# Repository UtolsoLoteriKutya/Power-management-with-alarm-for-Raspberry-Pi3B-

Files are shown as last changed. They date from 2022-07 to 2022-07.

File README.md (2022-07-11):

<html xmlns:v="urn:schemas-microsoft-com:vml"
xmlns:o="urn:schemas-microsoft-com:office:office"
xmlns:w="urn:schemas-microsoft-com:office:word"
xmlns:m="http://schemas.microsoft.com/office/2004/12/omml"
xmlns="http://www.w3.org/TR/REC-html40">

<head>
<meta http-equiv=Content-Type content="text/html; charset=windows-1250">
<meta name=ProgId content=Word.Document>
<meta name=Generator content="Microsoft Word 15">
<meta name=Originator content="Microsoft Word 15">
<link rel=File-List href="index_elemei/filelist.xml">
<link rel=Edit-Time-Data href="index_elemei/editdata.mso">
<!--[if !mso]>

<![endif]--><!--[if gte mso 9]><xml>
 <o:DocumentProperties>
  <o:Author>Citrák János</o:Author>
  <o:LastAuthor>Citrák János</o:LastAuthor>
  <o:Revision>5</o:Revision>
  <o:Created>2022-07-11T07:24:00Z</o:Created>
  <o:LastSaved>2022-07-11T10:03:00Z</o:LastSaved>
  <o:Pages>1</o:Pages>
  <o:Words>778</o:Words>
  <o:Characters>4903</o:Characters>
  <o:Lines>40</o:Lines>
  <o:Paragraphs>11</o:Paragraphs>
  <o:CharactersWithSpaces>5670</o:CharactersWithSpaces>
  <o:Version>16.00</o:Version>
 </o:DocumentProperties>
 <o:OfficeDocumentSettings>
  <o:AllowPNG/>
 </o:OfficeDocumentSettings>
</xml><![endif]-->
<link rel=themeData href="index_elemei/themedata.thmx">
<link rel=colorSchemeMapping href="index_elemei/colorschememapping.xml">
<!--[if gte mso 9]><xml>
 <w:WordDocument>
  <w:Zoom>90</w:Zoom>
  <w:TrackMoves>false</w:TrackMoves>
  <w:TrackFormatting/>
  <w:HyphenationZone>21</w:HyphenationZone>
  <w:PunctuationKerning/>
  <w:ValidateAgainstSchemas/>
  <w:SaveIfXMLInvalid>false</w:SaveIfXMLInvalid>
  <w:IgnoreMixedContent>false</w:IgnoreMixedContent>
  <w:AlwaysShowPlaceholderText>false</w:AlwaysShowPlaceholderText>
  <w:DoNotPromoteQF/>
  <w:LidThemeOther>DE</w:LidThemeOther>
  <w:LidThemeAsian>X-NONE</w:LidThemeAsian>
  <w:LidThemeComplexScript>AR-SA</w:LidThemeComplexScript>
  <w:Compatibility>
   <w:BreakWrappedTables/>
   <w:SnapToGridInCell/>
   <w:WrapTextWithPunct/>
   <w:UseAsianBreakRules/>
   <w:DontGrowAutofit/>
   <w:SplitPgBreakAndParaMark/>
   <w:EnableOpenTypeKerning/>
   <w:DontFlipMirrorIndents/>
   <w:OverrideTableStyleHps/>
  </w:Compatibility>
  <m:mathPr>
   <m:mathFont m:val="Cambria Math"/>
   <m:brkBin m:val="before"/>
   <m:brkBinSub m:val="&#45;-"/>
   <m:smallFrac m:val="off"/>
   <m:dispDef/>
   <m:lMargin m:val="0"/>
   <m:rMargin m:val="0"/>
   <m:defJc m:val="centerGroup"/>
   <m:wrapIndent m:val="1440"/>
   <m:intLim m:val="subSup"/>
   <m:naryLim m:val="undOvr"/>
  </m:mathPr></w:WordDocument>
</xml><![endif]--><!--[if gte mso 9]><xml>
 <w:LatentStyles DefLockedState="false" DefUnhideWhenUsed="false"
  DefSemiHidden="false" DefQFormat="false" DefPriority="99"
  LatentStyleCount="376">
  <w:LsdException Locked="false" Priority="0" QFormat="true" Name="Normal"/>
  <w:LsdException Locked="false" Priority="9" QFormat="true" Name="heading 1"/>
  <w:LsdException Locked="false" Priority="9" SemiHidden="true"
   UnhideWhenUsed="true" QFormat="true" Name="heading 2"/>
  <w:LsdException Locked="false" Priority="9" SemiHidden="true"
   UnhideWhenUsed="true" QFormat="true" Name="heading 3"/>
  <w:LsdException Locked="false" Priority="9" SemiHidden="true"
   UnhideWhenUsed="true" QFormat="true" Name="heading 4"/>
  <w:LsdException Locked="false" Priority="9" SemiHidden="true"
   UnhideWhenUsed="true" QFormat="true" Name="heading 5"/>
  <w:LsdException Locked="false" Priority="9" SemiHidden="true"
   UnhideWhenUsed="true" QFormat="true" Name="heading 6"/>
  <w:LsdException Locked="false" Priority="9" SemiHidden="true"
   UnhideWhenUsed="true" QFormat="true" Name="heading 7"/>
  <w:LsdException Locked="false" Priority="9" SemiHidden="true"
   UnhideWhenUsed="true" QFormat="true" Name="heading 8"/>
  <w:LsdException Locked="false" Priority="9" SemiHidden="true"
   UnhideWhenUsed="true" QFormat="true" Name="heading 9"/>
  <w:LsdException Locked="false" SemiHidden="true" UnhideWhenUsed="true"
   Name="index 1"/>
  <w:LsdException Locked="false" SemiHidden="true" UnhideWhenUsed="true"
   Name="index 2"/>
  <w:LsdException Locked="false" SemiHidden="true" UnhideWhenUsed="true"
   Name="index 3"/>
  <w:LsdException Locked="false" SemiHidden="true" UnhideWhenUsed="true"
   Name="index 4"/>
  <w:LsdException Locked="false" SemiHidden="true" UnhideWhenUsed="true"
   Name="index 5"/>
  <w:LsdException Locked="false" SemiHidden="true" UnhideWhenUsed="true"
   Name="index 6"/>
  <w:LsdException Locked="false" SemiHidden="true" UnhideWhenUsed="true"
   Name="index 7"/>
  <w:LsdException Locked="false" SemiHidden="true" UnhideWhenUsed="true"
   Name="index 8"/>
  <w:LsdException Locked="false" SemiHidden="true" UnhideWhenUsed="true"
   Name="index 9"/>
  <w:LsdException Locked="false" Priority="39" SemiHidden="true"
   UnhideWhenUsed="true" Name="toc 1"/>
  <w:LsdException Locked="false" Priority="39" SemiHidden="true"
   UnhideWhenUsed="true" Name="toc 2"/>
  <w:LsdException Locked="false" Priority="39" SemiHidden="true"
   UnhideWhenUsed="true" Name="toc 3"/>
  <w:LsdException Locked="false" Priority="39" SemiHidden="true"
   UnhideWhenUsed="true" Name="toc 4"/>
  <w:LsdException Locked="false" Priority="39" SemiHidden="true"
   UnhideWhenUsed="true" Name="toc 5"/>
  <w:LsdException Locked="false" Priority="39" SemiHidden="true"
   UnhideWhenUsed="true" Name="toc 6"/>
  <w:LsdException Locked="false" Priority="39" SemiHidden="true"
   UnhideWhenUsed="true" Name="toc 7"/>
  <w:LsdException Locked="false" Priority="39" SemiHidden="true"
   UnhideWhenUsed="true" Name="toc 8"/>
  <w:LsdException Locked="false" Priority="39" SemiHidden="true"
   UnhideWhenUsed="true" Name="toc 9"/>
  <w:LsdException Locked="false" SemiHidden="true" UnhideWhenUsed="true"
   Name="Normal Indent"/>
  <w:LsdException Locked="false" SemiHidden="true" UnhideWhenUsed="true"
   Name="footnote text"/>
  <w:LsdException Locked="false" SemiHidden="true" UnhideWhenUsed="true"
   Name="annotation text"/>
  <w:LsdException Locked="false" SemiHidden="true" UnhideWhenUsed="true"
   Name="header"/>
  <w:LsdException Locked="false" SemiHidden="true" UnhideWhenUsed="true"
   Name="footer"/>
  <w:LsdException Locked="false" SemiHidden="true" UnhideWhenUsed="true"
   Name="index heading"/>
  <w:LsdException Locked="false" Priority="35" SemiHidden="true"
   UnhideWhenUsed="true" QFormat="true" Name="caption"/>
  <w:LsdException Locked="false" SemiHidden="true" UnhideWhenUsed="true"
   Name="table of figures"/>
  <w:LsdException Locked="false" SemiHidden="true" UnhideWhenUsed="true"
   Name="envelope address"/>
  <w:LsdException Locked="false" SemiHidden="true" UnhideWhenUsed="true"
   Name="envelope return"/>
  <w:LsdException Locked="false" SemiHidden="true" UnhideWhenUsed="true"
   Name="footnote reference"/>
  <w:LsdException Locked="false" SemiHidden="true" UnhideWhenUsed="true"
   Name="annotation reference"/>
  <w:LsdException Locked="false" SemiHidden="true" UnhideWhenUsed="true"
   Name="line number"/>
  <w:LsdException Locked="false" SemiHidden="true" UnhideWhenUsed="true"
   Name="page number"/>
  <w:LsdException Locked="false" SemiHidden="true" UnhideWhenUsed="true"
   Name="endnote reference"/>
  <w:LsdException Locked="false" SemiHidden="true" UnhideWhenUsed="true"
   Name="endnote text"/>
  <w:LsdException Locked="false" SemiHidden="true" UnhideWhenUsed="true"
   Name="table of authorities"/>
  <w:LsdException Locked="false" SemiHidden="true" UnhideWhenUsed="true"
   Name="macro"/>
  <w:LsdException Locked="false" SemiHidden="true" UnhideWhenUsed="true"
   Name="toa heading"/>
  <w:LsdException Locked="false" SemiHidden="true" UnhideWhenUsed="true"
   Name="List"/>
  <w:LsdException Locked="false" SemiHidden="true" UnhideWhenUsed="true"
   Name="List Bullet"/>
  <w:LsdException Locked="false" SemiHidden="true" UnhideWhenUsed="true"
   Name="List Number"/>
  <w:LsdException Locked="false" SemiHidden="true" UnhideWhenUsed="true"
   Name="List 2"/>
  <w:LsdException Locked="false" SemiHidden="true" UnhideWhenUsed="true"
   Name="List 3"/>
  <w:LsdException Locked="false" SemiHidden="true" UnhideWhenUsed="true"
   Name="List 4"/>
  <w:LsdException Locked="false" SemiHidden="true" UnhideWhenUsed="true"
   Name="List 5"/>
  <w:LsdException Locked="false" SemiHidden="true" UnhideWhenUsed="true"
   Name="List Bullet 2"/>
  <w:LsdException Locked="false" SemiHidden="true" UnhideWhenUsed="true"
   Name="List Bullet 3"/>
  <w:LsdException Locked="false" SemiHidden="true" UnhideWhenUsed="true"
   Name="List Bullet 4"/>
  <w:LsdException Locked="false" SemiHidden="true" UnhideWhenUsed="true"
   Name="List Bullet 5"/>
  <w:LsdException Locked="false" SemiHidden="true" UnhideWhenUsed="true"
   Name="List Number 2"/>
  <w:LsdException Locked="false" SemiHidden="true" UnhideWhenUsed="true"
   Name="List Number 3"/>
  <w:LsdException Locked="false" SemiHidden="true" UnhideWhenUsed="true"
   Name="List Number 4"/>
  <w:LsdException Locked="false" SemiHidden="true" UnhideWhenUsed="true"
   Name="List Number 5"/>
  <w:LsdException Locked="false" Priority="10" QFormat="true" Name="Title"/>
  <w:LsdException Locked="false" SemiHidden="true" UnhideWhenUsed="true"
   Name="Closing"/>
  <w:LsdException Locked="false" SemiHidden="true" UnhideWhenUsed="true"
   Name="Signature"/>
  <w:LsdException Locked="false" Priority="1" SemiHidden="true"
   UnhideWhenUsed="true" Name="Default Paragraph Font"/>
  <w:LsdException Locked="false" SemiHidden="true" UnhideWhenUsed="true"
   Name="Body Text"/>
  <w:LsdException Locked="false" SemiHidden="true" UnhideWhenUsed="true"
   Name="Body Text Indent"/>
  <w:LsdException Locked="false" SemiHidden="true" UnhideWhenUsed="true"
   Name="List Continue"/>
  <w:LsdException Locked="false" SemiHidden="true" UnhideWhenUsed="true"
   Name="List Continue 2"/>
  <w:LsdException Locked="false" SemiHidden="true" UnhideWhenUsed="true"
   Name="List Continue 3"/>
  <w:LsdException Locked="false" SemiHidden="true" UnhideWhenUsed="true"
   Name="List Continue 4"/>
  <w:LsdException Locked="false" SemiHidden="true" UnhideWhenUsed="true"
   Name="List Continue 5"/>
  <w:LsdException Locked="false" SemiHidden="true" UnhideWhenUsed="true"
   Name="Message Header"/>
  <w:LsdException Locked="false" Priority="11" QFormat="true" Name="Subtitle"/>
  <w:LsdException Locked="false" SemiHidden="true" UnhideWhenUsed="true"
   Name="Salutation"/>
  <w:LsdException Locked="false" SemiHidden="true" UnhideWhenUsed="true"
   Name="Date"/>
  <w:LsdException Locked="false" SemiHidden="true" UnhideWhenUsed="true"
   Name="Body Text First Indent"/>
  <w:LsdException Locked="false" SemiHidden="true" UnhideWhenUsed="true"
   Name="Body Text First Indent 2"/>
  <w:LsdException Locked="false" SemiHidden="true" UnhideWhenUsed="true"
   Name="Note Heading"/>
  <w:LsdException Locked="false" SemiHidden="true" UnhideWhenUsed="true"
   Name="Body Text 2"/>
  <w:LsdException Locked="false" SemiHidden="true" UnhideWhenUsed="true"
   Name="Body Text 3"/>
  <w:LsdException Locked="false" SemiHidden="true" UnhideWhenUsed="true"
   Name="Body Text Indent 2"/>
  <w:LsdException Locked="false" SemiHidden="true" UnhideWhenUsed="true"
   Name="Body Text Indent 3"/>
  <w:LsdException Locked="false" SemiHidden="true" UnhideWhenUsed="true"
   Name="Block Text"/>
  <w:LsdException Locked="false" SemiHidden="true" UnhideWhenUsed="true"
   Name="Hyperlink"/>
  <w:LsdException Locked="false" SemiHidden="true" UnhideWhenUsed="true"
   Name="FollowedHyperlink"/>
  <w:LsdException Locked="false" Priority="22" QFormat="true" Name="Strong"/>
  <w:LsdException Locked="false" Priority="20" QFormat="true" Name="Emphasis"/>
  <w:LsdException Locked="false" SemiHidden="true" UnhideWhenUsed="true"
   Name="Document Map"/>
  <w:LsdException Locked="false" SemiHidden="true" UnhideWhenUsed="true"
   Name="Plain Text"/>
  <w:LsdException Locked="false" SemiHidden="true" UnhideWhenUsed="true"
   Name="E-mail Signature"/>
  <w:LsdException Locked="false" SemiHidden="true" UnhideWhenUsed="true"
   Name="HTML Top of Form"/>
  <w:LsdException Locked="false" SemiHidden="true" UnhideWhenUsed="true"
   Name="HTML Bottom of Form"/>
  <w:LsdException Locked="false" SemiHidden="true" UnhideWhenUsed="true"
   Name="Normal (Web)"/>
  <w:LsdException Locked="false" SemiHidden="true" UnhideWhenUsed="true"
   Name="HTML Acronym"/>
  <w:LsdException Locked="false" SemiHidden="true" UnhideWhenUsed="true"
   Name="HTML Address"/>
  <w:LsdException Locked="false" SemiHidden="true" UnhideWhenUsed="true"
   Name="HTML Cite"/>
  <w:LsdException Locked="false" SemiHidden="true" UnhideWhenUsed="true"
   Name="HTML Code"/>
  <w:LsdException Locked="false" SemiHidden="true" UnhideWhenUsed="true"
   Name="HTML Definition"/>
  <w:LsdException Locked="false" SemiHidden="true" UnhideWhenUsed="true"
   Name="HTML Keyboard"/>
  <w:LsdException Locked="false" SemiHidden="true" UnhideWhenUsed="true"
   Name="HTML Preformatted"/>
  <w:LsdException Locked="false" SemiHidden="true" UnhideWhenUsed="true"
   Name="HTML Sample"/>
  <w:LsdException Locked="false" SemiHidden="true" UnhideWhenUsed="true"
   Name="HTML Typewriter"/>
  <w:LsdException Locked="false" SemiHidden="true" UnhideWhenUsed="true"
   Name="HTML Variable"/>
  <w:LsdException Locked="false" SemiHidden="true" UnhideWhenUsed="true"
   Name="Normal Table"/>
  <w:LsdException Locked="false" SemiHidden="true" UnhideWhenUsed="true"
   Name="annotation subject"/>
  <w:LsdException Locked="false" SemiHidden="true" UnhideWhenUsed="true"
   Name="No List"/>
  <w:LsdException Locked="false" SemiHidden="true" UnhideWhenUsed="true"
   Name="Outline List 1"/>
  <w:LsdException Locked="false" SemiHidden="true" UnhideWhenUsed="true"
   Name="Outline List 2"/>
  <w:LsdException Locked="false" SemiHidden="true" UnhideWhenUsed="true"
   Name="Outline List 3"/>
  <w:LsdException Locked="false" SemiHidden="true" UnhideWhenUsed="true"
   Name="Table Simple 1"/>
  <w:LsdException Locked="false" SemiHidden="true" UnhideWhenUsed="true"
   Name="Table Simple 2"/>
  <w:LsdException Locked="false" SemiHidden="true" UnhideWhenUsed="true"
   Name="Table Simple 3"/>
  <w:LsdException Locked="false" SemiHidden="true" UnhideWhenUsed="true"
   Name="Table Classic 1"/>
  <w:LsdException Locked="false" SemiHidden="true" UnhideWhenUsed="true"
   Name="Table Classic 2"/>
  <w:LsdException Locked="false" SemiHidden="true" UnhideWhenUsed="true"
   Name="Table Classic 3"/>
  <w:LsdException Locked="false" SemiHidden="true" UnhideWhenUsed="true"
   Name="Table Classic 4"/>
  <w:LsdException Locked="false" SemiHidden="true" UnhideWhenUsed="true"
   Name="Table Colorful 1"/>
  <w:LsdException Locked="false" SemiHidden="true" UnhideWhenUsed="true"
   Name="Table Colorful 2"/>
  <w:LsdException Locked="false" SemiHidden="true" UnhideWhenUsed="true"
   Name="Table Colorful 3"/>
  <w:LsdException Locked="false" SemiHidden="true" UnhideWhenUsed="true"
   Name="Table Columns 1"/>
  <w:LsdException Locked="false" SemiHidden="true" UnhideWhenUsed="true"
   Name="Table Columns 2"/>
  <w:LsdException Locked="false" SemiHidden="true" UnhideWhenUsed="true"
   Name="Table Columns 3"/>
  <w:LsdException Locked="false" SemiHidden="true" UnhideWhenUsed="true"
   Name="Table Columns 4"/>
  <w:LsdException Locked="false" SemiHidden="true" UnhideWhenUsed="true"
   Name="Table Columns 5"/>
  <w:LsdException Locked="false" SemiHidden="true" UnhideWhenUsed="true"
   Name="Table Grid 1"/>
  <w:LsdException Locked="false" SemiHidden="true" UnhideWhenUsed="true"
   Name="Table Grid 2"/>
  <w:LsdException Locked="false" SemiHidden="true" UnhideWhenUsed="true"
   Name="Table Grid 3"/>
  <w:LsdException Locked="false" SemiHidden="true" UnhideWhenUsed="true"
   Name="Table Grid 4"/>
  <w:LsdException Locked="false" SemiHidden="true" UnhideWhenUsed="true"
   Name="Table Grid 5"/>
  <w:LsdException Locked="false" SemiHidden="true" UnhideWhenUsed="true"
   Name="Table Grid 6"/>
  <w:LsdException Locked="false" SemiHidden="true" UnhideWhenUsed="true"
   Name="Table Grid 7"/>
  <w:LsdException Locked="false" SemiHidden="true" UnhideWhenUsed="true"
   Name="Table Grid 8"/>
  <w:LsdException Locked="false" SemiHidden="true" UnhideWhenUsed="true"
   Name="Table List 1"/>
  <w:LsdException Locked="false" SemiHidden="true" UnhideWhenUsed="true"
   Name="Table List 2"/>
  <w:LsdException Locked="false" SemiHidden="true" UnhideWhenUsed="true"
   Name="Table List 3"/>
  <w:LsdException Locked="false" SemiHidden="true" UnhideWhenUsed="true"
   Name="Table List 4"/>
  <w:LsdException Locked="false" SemiHidden="true" UnhideWhenUsed="true"
   Name="Table List 5"/>
  <w:LsdException Locked="false" SemiHidden="true" UnhideWhenUsed="true"
   Name="Table List 6"/>
  <w:LsdException Locked="false" SemiHidden="true" UnhideWhenUsed="true"
   Name="Table List 7"/>
  <w:LsdException Locked="false" SemiHidden="true" UnhideWhenUsed="true"
   Name="Table List 8"/>
  <w:LsdException Locked="false" SemiHidden="true" UnhideWhenUsed="true"
   Name="Table 3D effects 1"/>
  <w:LsdException Locked="false" SemiHidden="true" UnhideWhenUsed="true"
   Name="Table 3D effects 2"/>
  <w:LsdException Locked="false" SemiHidden="true" UnhideWhenUsed="true"
   Name="Table 3D effects 3"/>
  <w:LsdException Locked="false" SemiHidden="true" UnhideWhenUsed="true"
   Name="Table Contemporary"/>
  <w:LsdException Locked="false" SemiHidden="true" UnhideWhenUsed="true"
   Name="Table Elegant"/>
  <w:LsdException Locked="false" SemiHidden="true" UnhideWhenUsed="true"
   Name="Table Professional"/>
  <w:LsdException Locked="false" SemiHidden="true" UnhideWhenUsed="true"
   Name="Table Subtle 1"/>
  <w:LsdException Locked="false" SemiHidden="true" UnhideWhenUsed="true"
   Name="Table Subtle 2"/>
  <w:LsdException Locked="false" SemiHidden="true" UnhideWhenUsed="true"
   Name="Table Web 1"/>
  <w:LsdException Locked="false" SemiHidden="true" UnhideWhenUsed="true"
   Name="Table Web 2"/>
  <w:LsdException Locked="false" SemiHidden="true" UnhideWhenUsed="true"
   Name="Table Web 3"/>
  <w:LsdException Locked="false" SemiHidden="true" UnhideWhenUsed="true"
   Name="Balloon Text"/>
  <w:LsdException Locked="false" Priority="39" Name="Table Grid"/>
  <w:LsdException Locked="false" SemiHidden="true" UnhideWhenUsed="true"
   Name="Table Theme"/>
  <w:LsdException Locked="false" SemiHidden="true" Name="Placeholder Text"/>
  <w:LsdException Locked="false" Priority="1" QFormat="true" Name="No Spacing"/>
  <w:LsdException Locked="false" Priority="60" Name="Light Shading"/>
  <w:LsdException Locked="false" Priority="61" Name="Light List"/>
  <w:LsdException Locked="false" Priority="62" Name="Light Grid"/>
  <w:LsdException Locked="false" Priority="63" Name="Medium Shading 1"/>
  <w:LsdException Locked="false" Priority="64" Name="Medium Shading 2"/>
  <w:LsdException Locked="false" Priority="65" Name="Medium List 1"/>
  <w:LsdException Locked="false" Priority="66" Name="Medium List 2"/>
  <w:LsdException Locked="false" Priority="67" Name="Medium Grid 1"/>
  <w:LsdException Locked="false" Priority="68" Name="Medium Grid 2"/>
  <w:LsdException Locked="false" Priority="69" Name="Medium Grid 3"/>
  <w:LsdException Locked="false" Priority="70" Name="Dark List"/>
  <w:LsdException Locked="false" Priority="71" Name="Colorful Shading"/>
  <w:LsdException Locked="false" Priority="72" Name="Colorful List"/>
  <w:LsdException Locked="false" Priority="73" Name="Colorful Grid"/>
  <w:LsdException Locked="false" Priority="60" Name="Light Shading Accent 1"/>
  <w:LsdException Locked="false" Priority="61" Name="Light List Accent 1"/>
  <w:LsdException Locked="false" Priority="62" Name="Light Grid Accent 1"/>
  <w:LsdException Locked="false" Priority="63" Name="Medium Shading 1 Accent 1"/>
  <w:LsdException Locked="false" Priority="64" Name="Medium Shading 2 Accent 1"/>
  <w:LsdException Locked="false" Priority="65" Name="Medium List 1 Accent 1"/>
  <w:LsdException Locked="false" SemiHidden="true" Name="Revision"/>
  <w:LsdException Locked="false" Priority="34" QFormat="true"
   Name="List Paragraph"/>
  <w:LsdException Locked="false" Priority="29" QFormat="true" Name="Quote"/>
  <w:LsdException Locked="false" Priority="30" QFormat="true"
   Name="Intense Quote"/>
  <w:LsdException Locked="false" Priority="66" Name="Medium List 2 Accent 1"/>
  <w:LsdException Locked="false" Priority="67" Name="Medium Grid 1 Accent 1"/>
  <w:LsdException Locked="false" Priority="68" Name="Medium Grid 2 Accent 1"/>
  <w:LsdException Locked="false" Priority="69" Name="Medium Grid 3 Accent 1"/>
  <w:LsdException Locked="false" Priority="70" Name="Dark List Accent 1"/>
  <w:LsdException Locked="false" Priority="71" Name="Colorful Shading Accent 1"/>
  <w:LsdException Locked="false" Priority="72" Name="Colorful List Accent 1"/>
  <w:LsdException Locked="false" Priority="73" Name="Colorful Grid Accent 1"/>
  <w:LsdException Locked="false" Priority="60" Name="Light Shading Accent 2"/>
  <w:LsdException Locked="false" Priority="61" Name="Light List Accent 2"/>
  <w:LsdException Locked="false" Priority="62" Name="Light Grid Accent 2"/>
  <w:LsdException Locked="false" Priority="63" Name="Medium Shading 1 Accent 2"/>
  <w:LsdException Locked="false" Priority="64" Name="Medium Shading 2 Accent 2"/>
  <w:LsdException Locked="false" Priority="65" Name="Medium List 1 Accent 2"/>
  <w:LsdException Locked="false" Priority="66" Name="Medium List 2 Accent 2"/>
  <w:LsdException Locked="false" Priority="67" Name="Medium Grid 1 Accent 2"/>
  <w:LsdException Locked="false" Priority="68" Name="Medium Grid 2 Accent 2"/>
  <w:LsdException Locked="false" Priority="69" Name="Medium Grid 3 Accent 2"/>
  <w:LsdException Locked="false" Priority="70" Name="Dark List Accent 2"/>
  <w:LsdException Locked="false" Priority="71" Name="Colorful Shading Accent 2"/>
  <w:LsdException Locked="false" Priority="72" Name="Colorful List Accent 2"/>
  <w:LsdException Locked="false" Priority="73" Name="Colorful Grid Accent 2"/>
  <w:LsdException Locked="false" Priority="60" Name="Light Shading Accent 3"/>
  <w:LsdException Locked="false" Priority="61" Name="Light List Accent 3"/>
  <w:LsdException Locked="false" Priority="62" Name="Light Grid Accent 3"/>
  <w:LsdException Locked="false" Priority="63" Name="Medium Shading 1 Accent 3"/>
  <w:LsdException Locked="false" Priority="64" Name="Medium Shading 2 Accent 3"/>
  <w:LsdException Locked="false" Priority="65" Name="Medium List 1 Accent 3"/>
  <w:LsdException Locked="false" Priority="66" Name="Medium List 2 Accent 3"/>
  <w:LsdException Locked="false" Priority="67" Name="Medium Grid 1 Accent 3"/>
  <w:LsdException Locked="false" Priority="68" Name="Medium Grid 2 Accent 3"/>
  <w:LsdException Locked="false" Priority="69" Name="Medium Grid 3 Accent 3"/>
  <w:LsdException Locked="false" Priority="70" Name="Dark List Accent 3"/>
  <w:LsdException Locked="false" Priority="71" Name="Colorful Shading Accent 3"/>
  <w:LsdException Locked="false" Priority="72" Name="Colorful List Accent 3"/>
  <w:LsdException Locked="false" Priority="73" Name="Colorful Grid Accent 3"/>
  <w:LsdException Locked="false" Priority="60" Name="Light Shading Accent 4"/>
  <w:LsdException Locked="false" Priority="61" Name="Light List Accent 4"/>
  <w:LsdException Locked="false" Priority="62" Name="Light Grid Accent 4"/>
  <w:LsdException Locked="false" Priority="63" Name="Medium Shading 1 Accent 4"/>
  <w:LsdException Locked="false" Priority="64" Name="Medium Shading 2 Accent 4"/>
  <w:LsdException Locked="false" Priority="65" Name="Medium List 1 Accent 4"/>
  <w:LsdException Locked="false" Priority="66" Name="Medium List 2 Accent 4"/>
  <w:LsdException Locked="false" Priority="67" Name="Medium Grid 1 Accent 4"/>
  <w:LsdException Locked="false" Priority="68" Name="Medium Grid 2 Accent 4"/>
  <w:LsdException Locked="false" Priority="69" Name="Medium Grid 3 Accent 4"/>
  <w:LsdException Locked="false" Priority="70" Name="Dark List Accent 4"/>
  <w:LsdException Locked="false" Priority="71" Name="Colorful Shading Accent 4"/>
  <w:LsdException Locked="false" Priority="72" Name="Colorful List Accent 4"/>
  <w:LsdException Locked="false" Priority="73" Name="Colorful Grid Accent 4"/>
  <w:LsdException Locked="false" Priority="60" Name="Light Shading Accent 5"/>
  <w:LsdException Locked="false" Priority="61" Name="Light List Accent 5"/>
  <w:LsdException Locked="false" Priority="62" Name="Light Grid Accent 5"/>
  <w:LsdException Locked="false" Priority="63" Name="Medium Shading 1 Accent 5"/>
  <w:LsdException Locked="false" Priority="64" Name="Medium Shading 2 Accent 5"/>
  <w:LsdException Locked="false" Priority="65" Name="Medium List 1 Accent 5"/>
  <w:LsdException Locked="false" Priority="66" Name="Medium List 2 Accent 5"/>
  <w:LsdException Locked="false" Priority="67" Name="Medium Grid 1 Accent 5"/>
  <w:LsdException Locked="false" Priority="68" Name="Medium Grid 2 Accent 5"/>
  <w:LsdException Locked="false" Priority="69" Name="Medium Grid 3 Accent 5"/>
  <w:LsdException Locked="false" Priority="70" Name="Dark List Accent 5"/>
  <w:LsdException Locked="false" Priority="71" Name="Colorful Shading Accent 5"/>
  <w:LsdException Locked="false" Priority="72" Name="Colorful List Accent 5"/>
  <w:LsdException Locked="false" Priority="73" Name="Colorful Grid Accent 5"/>
  <w:LsdException Locked="false" Priority="60" Name="Light Shading Accent 6"/>
  <w:LsdException Locked="false" Priority="61" Name="Light List Accent 6"/>
  <w:LsdException Locked="false" Priority="62" Name="Light Grid Accent 6"/>
  <w:LsdException Locked="false" Priority="63" Name="Medium Shading 1 Accent 6"/>
  <w:LsdException Locked="false" Priority="64" Name="Medium Shading 2 Accent 6"/>
  <w:LsdException Locked="false" Priority="65" Name="Medium List 1 Accent 6"/>
  <w:LsdException Locked="false" Priority="66" Name="Medium List 2 Accent 6"/>
  <w:LsdException Locked="false" Priority="67" Name="Medium Grid 1 Accent 6"/>
  <w:LsdException Locked="false" Priority="68" Name="Medium Grid 2 Accent 6"/>
  <w:LsdException Locked="false" Priority="69" Name="Medium Grid 3 Accent 6"/>
  <w:LsdException Locked="false" Priority="70" Name="Dark List Accent 6"/>
  <w:LsdException Locked="false" Priority="71" Name="Colorful Shading Accent 6"/>
  <w:LsdException Locked="false" Priority="72" Name="Colorful List Accent 6"/>
  <w:LsdException Locked="false" Priority="73" Name="Colorful Grid Accent 6"/>
  <w:LsdException Locked="false" Priority="19" QFormat="true"
   Name="Subtle Emphasis"/>
  <w:LsdException Locked="false" Priority="21" QFormat="true"
   Name="Intense Emphasis"/>
  <w:LsdException Locked="false" Priority="31" QFormat="true"
   Name="Subtle Reference"/>
  <w:LsdException Locked="false" Priority="32" QFormat="true"
   Name="Intense Reference"/>
  <w:LsdException Locked="false" Priority="33" QFormat="true" Name="Book Title"/>
  <w:LsdException Locked="false" Priority="37" SemiHidden="true"
   UnhideWhenUsed="true" Name="Bibliography"/>
  <w:LsdException Locked="false" Priority="39" SemiHidden="true"
   UnhideWhenUsed="true" QFormat="true" Name="TOC Heading"/>
  <w:LsdException Locked="false" Priority="41" Name="Plain Table 1"/>
  <w:LsdException Locked="false" Priority="42" Name="Plain Table 2"/>
  <w:LsdException Locked="false" Priority="43" Name="Plain Table 3"/>
  <w:LsdException Locked="false" Priority="44" Name="Plain Table 4"/>
  <w:LsdException Locked="false" Priority="45" Name="Plain Table 5"/>
  <w:LsdException Locked="false" Priority="40" Name="Grid Table Light"/>
  <w:LsdException Locked="false" Priority="46" Name="Grid Table 1 Light"/>
  <w:LsdException Locked="false" Priority="47" Name="Grid Table 2"/>
  <w:LsdException Locked="false" Priority="48" Name="Grid Table 3"/>
  <w:LsdException Locked="false" Priority="49" Name="Grid Table 4"/>
  <w:LsdException Locked="false" Priority="50" Name="Grid Table 5 Dark"/>
  <w:LsdException Locked="false" Priority="51" Name="Grid Table 6 Colorful"/>
  <w:LsdException Locked="false" Priority="52" Name="Grid Table 7 Colorful"/>
  <w:LsdException Locked="false" Priority="46"
   Name="Grid Table 1 Light Accent 1"/>
  <w:LsdException Locked="false" Priority="47" Name="Grid Table 2 Accent 1"/>
  <w:LsdException Locked="false" Priority="48" Name="Grid Table 3 Accent 1"/>
  <w:LsdException Locked="false" Priority="49" Name="Grid Table 4 Accent 1"/>
  <w:LsdException Locked="false" Priority="50" Name="Grid Table 5 Dark Accent 1"/>
  <w:LsdException Locked="false" Priority="51"
   Name="Grid Table 6 Colorful Accent 1"/>
  <w:LsdException Locked="false" Priority="52"
   Name="Grid Table 7 Colorful Accent 1"/>
  <w:LsdException Locked="false" Priority="46"
   Name="Grid Table 1 Light Accent 2"/>
  <w:LsdException Locked="false" Priority="47" Name="Grid Table 2 Accent 2"/>
  <w:LsdException Locked="false" Priority="48" Name="Grid Table 3 Accent 2"/>
  <w:LsdException Locked="false" Priority="49" Name="Grid Table 4 Accent 2"/>
  <w:LsdException Locked="false" Priority="50" Name="Grid Table 5 Dark Accent 2"/>
  <w:LsdException Locked="false" Priority="51"
   Name="Grid Table 6 Colorful Accent 2"/>
  <w:LsdException Locked="false" Priority="52"
   Name="Grid Table 7 Colorful Accent 2"/>
  <w:LsdException Locked="false" Priority="46"
   Name="Grid Table 1 Light Accent 3"/>
  <w:LsdException Locked="false" Priority="47" Name="Grid Table 2 Accent 3"/>
  <w:LsdException Locked="false" Priority="48" Name="Grid Table 3 Accent 3"/>
  <w:LsdException Locked="false" Priority="49" Name="Grid Table 4 Accent 3"/>
  <w:LsdException Locked="false" Priority="50" Name="Grid Table 5 Dark Accent 3"/>
  <w:LsdException Locked="false" Priority="51"
   Name="Grid Table 6 Colorful Accent 3"/>
  <w:LsdException Locked="false" Priority="52"
   Name="Grid Table 7 Colorful Accent 3"/>
  <w:LsdException Locked="false" Priority="46"
   Name="Grid Table 1 Light Accent 4"/>
  <w:LsdException Locked="false" Priority="47" Name="Grid Table 2 Accent 4"/>
  <w:LsdException Locked="false" Priority="48" Name="Grid Table 3 Accent 4"/>
  <w:LsdException Locked="false" Priority="49" Name="Grid Table 4 Accent 4"/>
  <w:LsdException Locked="false" Priority="50" Name="Grid Table 5 Dark Accent 4"/>
  <w:LsdException Locked="false" Priority="51"
   Name="Grid Table 6 Colorful Accent 4"/>
  <w:LsdException Locked="false" Priority="52"
   Name="Grid Table 7 Colorful Accent 4"/>
  <w:LsdException Locked="false" Priority="46"
   Name="Grid Table 1 Light Accent 5"/>
  <w:LsdException Locked="false" Priority="47" Name="Grid Table 2 Accent 5"/>
  <w:LsdException Locked="false" Priority="48" Name="Grid Table 3 Accent 5"/>
  <w:LsdException Locked="false" Priority="49" Name="Grid Table 4 Accent 5"/>
  <w:LsdException Locked="false" Priority="50" Name="Grid Table 5 Dark Accent 5"/>
  <w:LsdException Locked="false" Priority="51"
   Name="Grid Table 6 Colorful Accent 5"/>
  <w:LsdException Locked="false" Priority="52"
   Name="Grid Table 7 Colorful Accent 5"/>
  <w:LsdException Locked="false" Priority="46"
   Name="Grid Table 1 Light Accent 6"/>
  <w:LsdException Locked="false" Priority="47" Name="Grid Table 2 Accent 6"/>
  <w:LsdException Locked="false" Priority="48" Name="Grid Table 3 Accent 6"/>
  <w:LsdException Locked="false" Priority="49" Name="Grid Table 4 Accent 6"/>
  <w:LsdException Locked="false" Priority="50" Name="Grid Table 5 Dark Accent 6"/>
  <w:LsdException Locked="false" Priority="51"
   Name="Grid Table 6 Colorful Accent 6"/>
  <w:LsdException Locked="false" Priority="52"
   Name="Grid Table 7 Colorful Accent 6"/>
  <w:LsdException Locked="false" Priority="46" Name="List Table 1 Light"/>
  <w:LsdException Locked="false" Priority="47" Name="List Table 2"/>
  <w:LsdException Locked="false" Priority="48" Name="List Table 3"/>
  <w:LsdException Locked="false" Priority="49" Name="List Table 4"/>
  <w:LsdException Locked="false" Priority="50" Name="List Table 5 Dark"/>
  <w:LsdException Locked="false" Priority="51" Name="List Table 6 Colorful"/>
  <w:LsdException Locked="false" Priority="52" Name="List Table 7 Colorful"/>
  <w:LsdException Locked="false" Priority="46"
   Name="List Table 1 Light Accent 1"/>
  <w:LsdException Locked="false" Priority="47" Name="List Table 2 Accent 1"/>
  <w:LsdException Locked="false" Priority="48" Name="List Table 3 Accent 1"/>
  <w:LsdException Locked="false" Priority="49" Name="List Table 4 Accent 1"/>
  <w:LsdException Locked="false" Priority="50" Name="List Table 5 Dark Accent 1"/>
  <w:LsdException Locked="false" Priority="51"
   Name="List Table 6 Colorful Accent 1"/>
  <w:LsdException Locked="false" Priority="52"
   Name="List Table 7 Colorful Accent 1"/>
  <w:LsdException Locked="false" Priority="46"
   Name="List Table 1 Light Accent 2"/>
  <w:LsdException Locked="false" Priority="47" Name="List Table 2 Accent 2"/>
  <w:LsdException Locked="false" Priority="48" Name="List Table 3 Accent 2"/>
  <w:LsdException Locked="false" Priority="49" Name="List Table 4 Accent 2"/>
  <w:LsdException Locked="false" Priority="50" Name="List Table 5 Dark Accent 2"/>
  <w:LsdException Locked="false" Priority="51"
   Name="List Table 6 Colorful Accent 2"/>
  <w:LsdException Locked="false" Priority="52"
   Name="List Table 7 Colorful Accent 2"/>
  <w:LsdException Locked="false" Priority="46"
   Name="List Table 1 Light Accent 3"/>
  <w:LsdException Locked="false" Priority="47" Name="List Table 2 Accent 3"/>
  <w:LsdException Locked="false" Priority="48" Name="List Table 3 Accent 3"/>
  <w:LsdException Locked="false" Priority="49" Name="List Table 4 Accent 3"/>
  <w:LsdException Locked="false" Priority="50" Name="List Table 5 Dark Accent 3"/>
  <w:LsdException Locked="false" Priority="51"
   Name="List Table 6 Colorful Accent 3"/>
  <w:LsdException Locked="false" Priority="52"
   Name="List Table 7 Colorful Accent 3"/>
  <w:LsdException Locked="false" Priority="46"
   Name="List Table 1 Light Accent 4"/>
  <w:LsdException Locked="false" Priority="47" Name="List Table 2 Accent 4"/>
  <w:LsdException Locked="false" Priority="48" Name="List Table 3 Accent 4"/>
  <w:LsdException Locked="false" Priority="49" Name="List Table 4 Accent 4"/>
  <w:LsdException Locked="false" Priority="50" Name="List Table 5 Dark Accent 4"/>
  <w:LsdException Locked="false" Priority="51"
   Name="List Table 6 Colorful Accent 4"/>
  <w:LsdException Locked="false" Priority="52"
   Name="List Table 7 Colorful Accent 4"/>
  <w:LsdException Locked="false" Priority="46"
   Name="List Table 1 Light Accent 5"/>
  <w:LsdException Locked="false" Priority="47" Name="List Table 2 Accent 5"/>
  <w:LsdException Locked="false" Priority="48" Name="List Table 3 Accent 5"/>
  <w:LsdException Locked="false" Priority="49" Name="List Table 4 Accent 5"/>
  <w:LsdException Locked="false" Priority="50" Name="List Table 5 Dark Accent 5"/>
  <w:LsdException Locked="false" Priority="51"
   Name="List Table 6 Colorful Accent 5"/>
  <w:LsdException Locked="false" Priority="52"
   Name="List Table 7 Colorful Accent 5"/>
  <w:LsdException Locked="false" Priority="46"
   Name="List Table 1 Light Accent 6"/>
  <w:LsdException Locked="false" Priority="47" Name="List Table 2 Accent 6"/>
  <w:LsdException Locked="false" Priority="48" Name="List Table 3 Accent 6"/>
  <w:LsdException Locked="false" Priority="49" Name="List Table 4 Accent 6"/>
  <w:LsdException Locked="false" Priority="50" Name="List Table 5 Dark Accent 6"/>
  <w:LsdException Locked="false" Priority="51"
   Name="List Table 6 Colorful Accent 6"/>
  <w:LsdException Locked="false" Priority="52"
   Name="List Table 7 Colorful Accent 6"/>
  <w:LsdException Locked="false" SemiHidden="true" UnhideWhenUsed="true"
   Name="Mention"/>
  <w:LsdException Locked="false" SemiHidden="true" UnhideWhenUsed="true"
   Name="Smart Hyperlink"/>
  <w:LsdException Locked="false" SemiHidden="true" UnhideWhenUsed="true"
   Name="Hashtag"/>
  <w:LsdException Locked="false" SemiHidden="true" UnhideWhenUsed="true"
   Name="Unresolved Mention"/>
  <w:LsdException Locked="false" SemiHidden="true" UnhideWhenUsed="true"
   Name="Smart Link"/>
 </w:LatentStyles>
</xml><![endif]-->
<style>
<!--
 /* Font Definitions */
 @font-face
	{font-family:"Cambria Math";
	panose-1:2 4 5 3 5 4 6 3 2 4;
	mso-font-charset:238;
	mso-generic-font-family:roman;
	mso-font-pitch:variable;
	mso-font-signature:-536869121 1107305727 33554432 0 415 0;}
@font-face
	{font-family:Calibri;
	panose-1:2 15 5 2 2 2 4 3 2 4;
	mso-font-charset:238;
	mso-generic-font-family:swiss;
	mso-font-pitch:variable;
	mso-font-signature:-536859905 -1073732485 9 0 511 0;}
 /* Style Definitions */
 p.MsoNormal, li.MsoNormal, div.MsoNormal
	{mso-style-unhide:no;
	mso-style-qformat:yes;
	mso-style-parent:"";
	margin-top:0cm;
	margin-right:0cm;
	margin-bottom:8.0pt;
	margin-left:0cm;
	line-height:107%;
	mso-pagination:widow-orphan;
	font-size:11.0pt;
	font-family:"Calibri",sans-serif;
	mso-ascii-font-family:Calibri;
	mso-ascii-theme-font:minor-latin;
	mso-fareast-font-family:Calibri;
	mso-fareast-theme-font:minor-latin;
	mso-hansi-font-family:Calibri;
	mso-hansi-theme-font:minor-latin;
	mso-bidi-font-family:Arial;
	mso-bidi-theme-font:minor-bidi;
	mso-fareast-language:EN-US;}
a:link, span.MsoHyperlink
	{mso-style-priority:99;
	color:#0563C1;
	mso-themecolor:hyperlink;
	text-decoration:underline;
	text-underline:single;}
a:visited, span.MsoHyperlinkFollowed
	{mso-style-noshow:yes;
	mso-style-priority:99;
	color:#954F72;
	mso-themecolor:followedhyperlink;
	text-decoration:underline;
	text-underline:single;}
.MsoChpDefault
	{mso-style-type:export-only;
	mso-default-props:yes;
	font-family:"Calibri",sans-serif;
	mso-ascii-font-family:Calibri;
	mso-ascii-theme-font:minor-latin;
	mso-fareast-font-family:Calibri;
	mso-fareast-theme-font:minor-latin;
	mso-hansi-font-family:Calibri;
	mso-hansi-theme-font:minor-latin;
	mso-bidi-font-family:Arial;
	mso-bidi-theme-font:minor-bidi;
	mso-fareast-language:EN-US;}
.MsoPapDefault
	{mso-style-type:export-only;
	margin-bottom:8.0pt;
	line-height:107%;}
@page WordSection1
	{size:595.3pt 841.9pt;
	margin:70.85pt 70.85pt 2.0cm 70.85pt;
	mso-header-margin:35.4pt;
	mso-footer-margin:35.4pt;
	mso-paper-source:0;}
div.WordSection1
	{page:WordSection1;}
-->
</style>
<!--[if gte mso 10]>
<style>
 /* Style Definitions */
 table.MsoNormalTable
	{mso-style-name:"Normál táblázat";
	mso-tstyle-rowband-size:0;
	mso-tstyle-colband-size:0;
	mso-style-noshow:yes;
	mso-style-priority:99;
	mso-style-parent:"";
	mso-padding-alt:0cm 5.4pt 0cm 5.4pt;
	mso-para-margin-top:0cm;
	mso-para-margin-right:0cm;
	mso-para-margin-bottom:8.0pt;
	mso-para-margin-left:0cm;
	line-height:107%;
	mso-pagination:widow-orphan;
	font-size:11.0pt;
	font-family:"Calibri",sans-serif;
	mso-ascii-font-family:Calibri;
	mso-ascii-theme-font:minor-latin;
	mso-hansi-font-family:Calibri;
	mso-hansi-theme-font:minor-latin;
	mso-bidi-font-family:Arial;
	mso-bidi-theme-font:minor-bidi;
	mso-fareast-language:EN-US;}
</style>
<![endif]--><!--[if gte mso 9]><xml>
 <o:shapedefaults v:ext="edit" spidmax="1026"/>
</xml><![endif]--><!--[if gte mso 9]><xml>
 <o:shapelayout v:ext="edit">
  <o:idmap v:ext="edit" data="1"/>
 </o:shapelayout></xml><![endif]-->
</head>

<body lang=DE link="#0563C1" vlink="#954F72" style='tab-interval:35.4pt'>

<div class=WordSection1>

<p class=MsoNormal><b><span lang=EN-TT style='font-size:14.0pt;line-height:
107%;mso-ansi-language:EN-TT'><o:p>&nbsp;</o:p></span></b></p>

<p class=MsoNormal><b><span lang=EN-TT style='font-size:14.0pt;line-height:
107%;mso-ansi-language:EN-TT;mso-no-proof:yes'><!--[if gte vml 1]><v:shapetype
 id="_x0000_t75" coordsize="21600,21600" o:spt="75" o:preferrelative="t"
 path="m@4@5l@4@11@9@11@9@5xe" filled="f" stroked="f">
 <v:stroke joinstyle="miter"/>
 <v:formulas>
  <v:f eqn="if lineDrawn pixelLineWidth 0"/>
  <v:f eqn="sum @0 1 0"/>
  <v:f eqn="sum 0 0 @1"/>
  <v:f eqn="prod @2 1 2"/>
  <v:f eqn="prod @3 21600 pixelWidth"/>
  <v:f eqn="prod @3 21600 pixelHeight"/>
  <v:f eqn="sum @0 0 1"/>
  <v:f eqn="prod @6 1 2"/>
  <v:f eqn="prod @7 21600 pixelWidth"/>
  <v:f eqn="sum @8 21600 0"/>
  <v:f eqn="prod @7 21600 pixelHeight"/>
  <v:f eqn="sum @10 21600 0"/>
 </v:formulas>
 <v:path o:extrusionok="f" gradientshapeok="t" o:connecttype="rect"/>
 <o:lock v:ext="edit" aspectratio="t"/>
</v:shapetype><v:shape id="Kép_x0020_2" o:spid="_x0000_i1030" type="#_x0000_t75"
 alt="A képen szöveg, óra, idő, csatlakoztatott látható&#10;&#10;Automatikusan generált leírás"
 style='width:424.5pt;height:192.75pt;visibility:visible;mso-wrap-style:square'>
 <v:imagedata src="index_elemei/image001.jpg" o:title="A képen szöveg, óra, idő, csatlakoztatott látható&#10;&#10;Automatikusan generált leírás"/>
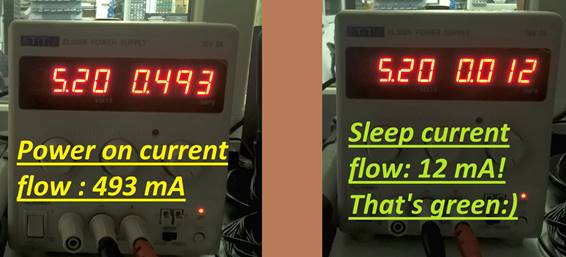
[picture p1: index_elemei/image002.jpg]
A képen szöveg, óra, idő, csatlakoztatott látható Automatikusan generált leírás
</v:shape><![endif]--><![if !vml]><![endif]><!--[if gte vml 1]><v:shape id="Kép_x0020_1"
 o:spid="_x0000_i1029" type="#_x0000_t75" alt="A képen szöveg látható&#10;&#10;Automatikusan generált leírás"
 style='width:342pt;height:192.75pt;rotation:180;visibility:visible;
 mso-wrap-style:square'>
 <v:imagedata src="index_elemei/image003.jpg" o:title="A képen szöveg látható&#10;&#10;Automatikusan generált leírás"/>
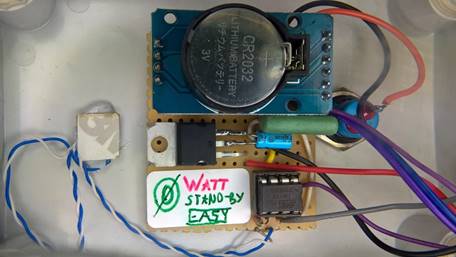
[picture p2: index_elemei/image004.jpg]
</v:shape><![endif]--><![if !vml]><![endif]></span></b><b><span
lang=EN-TT style='font-size:14.0pt;line-height:107%;mso-ansi-language:EN-TT'><o:p></o:p></span></b></p>

<p class=MsoNormal><b><span lang=EN-TT style='font-size:14.0pt;line-height:
107%;mso-ansi-language:EN-TT'><o:p>&nbsp;</o:p></span></b></p>

<p class=MsoNormal><b><span lang=EN-TT style='font-size:14.0pt;line-height:
107%;mso-ansi-language:EN-TT'>This page describes an extension to the new kind
of Raspberry Pi's to achieve &quot;PC-kind&quot; power management. The benefits
of it:</span></b><span lang=EN-TT style='font-size:14.0pt;line-height:107%;
mso-ansi-language:EN-TT'><o:p></o:p></span></p>

<p class=MsoNormal><span lang=EN-TT style='font-size:12.0pt;line-height:107%;
mso-ansi-language:EN-TT'><span style='mso-tab-count:1'>            </span>-<span
style='mso-tab-count:1'>           </span>Fully functioned power button<o:p></o:p></span></p>

<p class=MsoNormal><span lang=EN-TT style='font-size:12.0pt;line-height:107%;
mso-ansi-language:EN-TT'><span style='mso-tab-count:1'>            </span>-<span
style='mso-tab-count:1'>           </span>Achieving the board's low power
construction feature<o:p></o:p></span></p>

<p class=MsoNormal><span lang=EN-TT style='font-size:12.0pt;line-height:107%;
mso-ansi-language:EN-TT'><span style='mso-tab-count:1'>            </span>-<span
style='mso-tab-count:1'>           </span>additional RTC<span style='mso-tab-count:
1'> </span><o:p></o:p></span></p>

<p class=MsoNormal><span lang=EN-TT style='font-size:12.0pt;line-height:107%;
mso-ansi-language:EN-TT'><span style='mso-tab-count:1'>            </span>-<span
style='mso-tab-count:1'>           </span>programmable wake up<o:p></o:p></span></p>

<p class=MsoNormal><span lang=EN-TT style='font-size:12.0pt;line-height:107%;
mso-ansi-language:EN-TT'><o:p>&nbsp;</o:p></span></p>

<p class=MsoNormal><b><span lang=EN-TT style='font-size:12.0pt;line-height:
107%;mso-ansi-language:EN-TT'>Applicable boards as it is (tested):<o:p></o:p></span></b></p>

<p class=MsoNormal><span lang=EN-TT style='mso-ansi-language:EN-TT'><span
style='mso-tab-count:1'>                </span>-<span style='mso-tab-count:
1'>              </span>Raspberry Pi3 b+<o:p></o:p></span></p>

<p class=MsoNormal><span lang=EN-TT style='mso-ansi-language:EN-TT'><span
style='mso-tab-count:1'>                </span>-<span style='mso-tab-count:
1'>              </span>Raspberry Pi4<o:p></o:p></span></p>

<p class=MsoNormal><span lang=EN-TT style='mso-ansi-language:EN-TT'><o:p>&nbsp;</o:p></span></p>

<p class=MsoNormal><b><span lang=EN-TT style='font-size:12.0pt;line-height:
107%;mso-ansi-language:EN-TT'>Probably applicable with some modification (check
the description in the end of the page):<o:p></o:p></span></b></p>

<p class=MsoNormal><span lang=EN-TT style='mso-ansi-language:EN-TT'><span
style='mso-tab-count:1'>                </span>-<span style='mso-tab-count:
1'>              </span>Most of the older boards<o:p></o:p></span></p>

<p class=MsoNormal><span lang=EN-TT style='mso-ansi-language:EN-TT'><o:p>&nbsp;</o:p></span></p>

<p class=MsoNormal><b><u><span lang=EN-TT style='font-size:14.0pt;line-height:
107%;mso-ansi-language:EN-TT'>What hardware do you need over the Rpi:<o:p></o:p></span></u></b></p>

<p class=MsoNormal><span lang=EN-TT style='mso-ansi-language:EN-TT'><span
style='mso-tab-count:1'>                </span>-<span style='mso-tab-count:
1'>              </span>Attiny 13 + programmer + IDE<o:p></o:p></span></p>

<p class=MsoNormal><span lang=EN-TT style='mso-ansi-language:EN-TT'><span
style='mso-tab-count:1'>                </span>-<span style='mso-tab-count:
1'>              </span>few discrete components (take a look to the schematics)<o:p></o:p></span></p>

<p class=MsoNormal><span lang=EN-TT style='mso-ansi-language:EN-TT'><span
style='mso-tab-count:1'>                </span>-<span style='mso-tab-count:
1'>              </span>DS3231 IC with external components or complete module<o:p></o:p></span></p>

<p class=MsoNormal><u><span lang=EN-TT style='mso-ansi-language:EN-TT'><o:p><span
 style='text-decoration:none'>&nbsp;</span></o:p></span></u></p>

<p class=MsoNormal><b><u><span lang=EN-TT style='font-size:14.0pt;line-height:
107%;mso-ansi-language:EN-TT'>Background<o:p></o:p></span></u></b></p>

<p class=MsoNormal><span lang=EN-TT style='mso-ansi-language:EN-TT'><o:p>&nbsp;</o:p></span></p>

<p class=MsoNormal><span lang=EN-TT style='mso-ansi-language:EN-TT'>As many of
us experienced, the Raspberry pi's are very versatile small computers with a
lot of advantages and few drawbacks. One of the few ones -however depending the
field of use-<span style='mso-spacerun:yes'>  </span>is the lack of power
management possibilities. Since the enhanced version of the Pi3 has been introduced
to the market (Pi3 B+) the creators let the possibility for the users to
disable the internal regulators to save up energy. This additional uC
controlled unit handles it with some extended feature.<o:p></o:p></span></p>

<p class=MsoNormal><u><span lang=EN-TT style='mso-ansi-language:EN-TT'><o:p><span
 style='text-decoration:none'>&nbsp;</span></o:p></span></u></p>

<p class=MsoNormal><b><u><span lang=EN-TT style='font-size:14.0pt;line-height:
107%;mso-ansi-language:EN-TT'>Block diagram &amp; description<o:p></o:p></span></u></b></p>

<p class=MsoNormal><span lang=EN-TT style='mso-ansi-language:EN-TT'><o:p>&nbsp;</o:p></span></p>

<p class=MsoNormal><span lang=EN-TT style='mso-ansi-language:EN-TT;mso-no-proof:
yes'><!--[if gte vml 1]><v:shape id="Kép_x0020_3" o:spid="_x0000_i1028" type="#_x0000_t75"
 style='width:828.75pt;height:410.25pt;visibility:visible;mso-wrap-style:square'>
 <v:imagedata src="index_elemei/image007.png" o:title=""/>
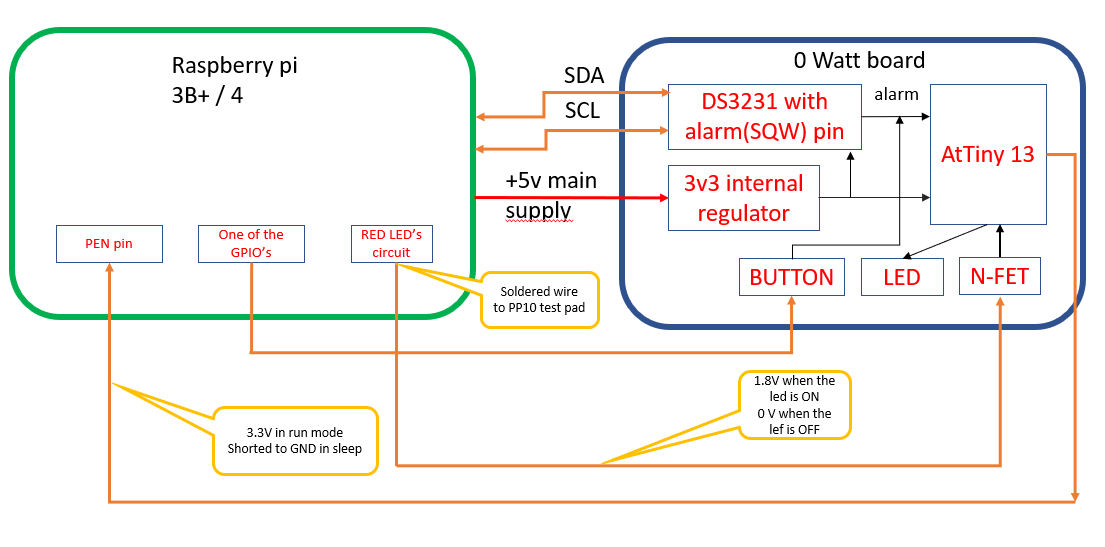
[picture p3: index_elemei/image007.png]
</v:shape><![endif]--><![if !vml]><![endif]></span><span
lang=EN-TT style='mso-ansi-language:EN-TT'><o:p></o:p></span></p>

<p class=MsoNormal><span lang=EN-TT style='mso-ansi-language:EN-TT'><o:p>&nbsp;</o:p></span></p>

<p class=MsoNormal><span lang=EN-TT style='mso-ansi-language:EN-TT'>The 0 Watt
PCB contains the few necessary parts what the project needs. The Attiny13 uC
senses the actual state of the Raspberry via the Power LED. (The led should be
off when the rpi works - it's configurable by the config.txt) If the Power led
is off it means for the uC that the system is working. When you shut it down by
command/click/gpio the red led starts to light again. It means that after a
certain amount of time (~ half minute ; can be modified in the Tiny’s code) the
regulators can be switched off (the Tiny pulls down the PEN connector) because
the Raspbian turned off the computer safely. <o:p></o:p></span></p>

<p class=MsoNormal><span lang=EN-TT style='mso-ansi-language:EN-TT'><o:p>&nbsp;</o:p></span></p>

<p class=MsoNormal><span lang=EN-TT style='mso-ansi-language:EN-TT'>The power
on process is initialized by the DS module's SQW pin or manually with the power
button. When it happens the Tiny releases the PEN pin, and waits (~ half
minute) for LED's switched down state. (If it fails for some reason it makes
the rpi fall back to sleep mode)<o:p></o:p></span></p>

<p class=MsoNormal><span lang=EN-TT style='mso-ansi-language:EN-TT'><o:p>&nbsp;</o:p></span></p>

<p class=MsoNormal><span lang=EN-TT style='mso-ansi-language:EN-TT'>The power
button has got two functions. One is to manually generate an interrupt to wake
up the system, the other is to create a signal for the Rpi (via the GPIO) to
shut down if it's pressed during the on state.<o:p></o:p></span></p>

<p class=MsoNormal><span lang=EN-TT style='mso-ansi-language:EN-TT'><o:p>&nbsp;</o:p></span></p>

<p class=MsoNormal><b><u><span lang=EN-TT style='font-size:14.0pt;line-height:
107%;mso-ansi-language:EN-TT'>Hardware construction<o:p></o:p></span></u></b></p>

<p class=MsoNormal><span lang=EN-TT style='mso-ansi-language:EN-TT'><o:p>&nbsp;</o:p></span></p>

<p class=MsoNormal><span lang=EN-TT style='mso-ansi-language:EN-TT'>A sample
schematic and PCB layout have been provided. The 3v3 regulator is needed to
give power for the uC and the RTC, because the Rpi's one is in shutdown mode
when the computer sleeps. It's possible to skip the regulator and make the
devices work from 5V directly, but in this case the level shift issue should be
handled on the i2c bus. The MOSFET converts the voltage level from 1.8V to the
uC's supply voltage, and also inverts the state. The signal's wire should be
soldered to the PP10 point of the Rpi of which located on the downside, close
to the LEDs. The diodes prevent to &quot;mix&quot; the Rpi and the boards 3,3Volt
voltages. The Attiny13's source code is provided, so you can modify by your own
if there is a need to change the behaviour of it.<o:p></o:p></span></p>

<p class=MsoNormal><span lang=EN-TT style='mso-ansi-language:EN-TT'>Sw modifications.<o:p></o:p></span></p>

<p class=MsoNormal><span lang=EN-TT style='mso-ansi-language:EN-TT'>These steps
have to be constructed:<o:p></o:p></span></p>

<p class=MsoNormal><i><span lang=EN-TT style='mso-ansi-language:EN-TT'><span
style='mso-tab-count:1'>                </span>1.<span style='mso-tab-count:
1'>            </span>Replacing the hwclock to the rtcctl because the original
one doesn't make ability to set the alarm.<o:p></o:p></span></i></p>

<p class=MsoNormal><i><span lang=EN-TT style='mso-ansi-language:EN-TT'><span
style='mso-tab-count:1'>                </span>2.<span style='mso-tab-count:
1'>            </span>To make the power led off when it boots.<o:p></o:p></span></i></p>

<p class=MsoNormal><i><span lang=EN-TT style='mso-ansi-language:EN-TT'><span
style='mso-tab-count:1'>                </span>3.<span style='mso-tab-count:
1'>            </span>Polling the power button.<o:p></o:p></span></i></p>

<p class=MsoNormal><b><span lang=EN-TT style='mso-ansi-language:EN-TT'>1.
Rtcctl install and config<o:p></o:p></span></b></p>

<p class=MsoNormal><span lang=EN-TT style='mso-ansi-language:EN-TT'>The RTCCTL
is a very smart application made by bablokb. You can download and install here
from <a href="https://github.com/bablokb/pi-wake-on-rtc">Github</a>. The site
mentions and I would like to emphasize too that you have to comment the “dtoverlay=i2c-rtc,ds3231”
line in the config.txt, to &quot;free up&quot; the hardware for this new
program.<o:p></o:p></span></p>

<p class=MsoNormal><span lang=EN-TT style='mso-ansi-language:EN-TT;mso-no-proof:
yes'><!--[if gte vml 1]><v:shape id="Kép_x0020_7" o:spid="_x0000_i1027" type="#_x0000_t75"
 alt="A képen szöveg látható&#10;&#10;Automatikusan generált leírás" style='width:178.5pt;
 height:50.25pt;visibility:visible;mso-wrap-style:square'>
 <v:imagedata src="index_elemei/image008.jpg" o:title="A képen szöveg látható&#10;&#10;Automatikusan generált leírás"/>
</v:shape><![endif]--><![if !vml]>A képen szöveg látható Automatikusan generált leírás<![endif]></span><span
lang=EN-TT style='mso-ansi-language:EN-TT'><o:p></o:p></span></p>

<p class=MsoNormal><span lang=EN-TT style='mso-ansi-language:EN-TT'>Syncing the
system time to the DS's clock. Hence there is no hwclock, and this function is
not automated in the rtcctl, it's advised to run it once at every boot
procedure like adding a line to the rc.local. Due to the DS3231's behaviour,
you have to manually clear the alarm register after it happened. It's also nice
to handle it at boot. Let’s see these extensions:<o:p></o:p></span></p>

<p class=MsoNormal><span lang=EN-TT style='mso-ansi-language:EN-TT'>If there is
more accurate time source like NTP, GPS, DCF77 in the system, it's advised to
periodically sync the DS's clock to the system time. The easiest way to add a
line to the /etc/crontab file like here, where it synchronizes at every :13
minutes of a hour.<o:p></o:p></span></p>

<p class=MsoNormal><span lang=EN-TT style='mso-ansi-language:EN-TT;mso-no-proof:
yes'><!--[if gte vml 1]><v:shape id="Kép_x0020_6" o:spid="_x0000_i1026" type="#_x0000_t75"
 alt="A képen szöveg látható&#10;&#10;Automatikusan generált leírás" style='width:693.75pt;
 height:111pt;visibility:visible;mso-wrap-style:square'>
 <v:imagedata src="index_elemei/image009.png" o:title="A képen szöveg látható&#10;&#10;Automatikusan generált leírás"/>
</v:shape><![endif]--><![if !vml]>A képen szöveg látható Automatikusan generált leírás<![endif]></span><span
lang=EN-TT style='mso-ansi-language:EN-TT'><o:p></o:p></span></p>

<p class=MsoNormal><b><span lang=EN-TT style='mso-ansi-language:EN-TT'>2.
Switching off the LED when it succesfully booted<o:p></o:p></span></b></p>

<p class=MsoNormal><span lang=EN-TT style='mso-ansi-language:EN-TT'>It can be
done by adding these two lines to the /etc/boot/config.txt:<o:p></o:p></span></p>

<p class=MsoNormal><span lang=EN-TT style='mso-ansi-language:EN-TT;mso-no-proof:
yes'><!--[if gte vml 1]><v:shape id="Kép_x0020_5" o:spid="_x0000_i1025" type="#_x0000_t75"
 style='width:3in;height:32.25pt;visibility:visible;mso-wrap-style:square'>
 <v:imagedata src="index_elemei/image010.jpg" o:title=""/>
</v:shape><![endif]--><![if !vml]><![endif]></span><span
lang=EN-TT style='mso-ansi-language:EN-TT'><o:p></o:p></span></p>

<p class=MsoNormal><b><span lang=EN-TT style='mso-ansi-language:EN-TT'>3.
Polling the power button<o:p></o:p></span></b></p>

<p class=MsoNormal><span lang=EN-TT style='mso-ansi-language:EN-TT'>There is a
way to do it by the OS (also enabling it in the config.txt) or making an own
program / integrate it to your main one. I have chosen the second option,
because with it I can also demonstrate an example for the alarm setting. You
can find my sample code in the repository.<o:p></o:p></span></p>

<p class=MsoNormal><b><u><span lang=EN-TT style='font-size:14.0pt;line-height:
107%;mso-ansi-language:EN-TT'>Additional notes<o:p></o:p></span></u></b></p>

<p class=MsoNormal><span lang=EN-TT style='mso-ansi-language:EN-TT'><o:p>&nbsp;</o:p></span></p>

<p class=MsoNormal><span lang=EN-TT style='mso-ansi-language:EN-TT'>-<span
style='mso-tab-count:1'>              </span>The whole current flowing in the
Vin(5V) is only ~12-14mA in sleep state. It's advised to use low quiescent
current LDO models to ensure this power consumption or get even lower.<o:p></o:p></span></p>

<p class=MsoNormal><span lang=EN-TT style='mso-ansi-language:EN-TT'>-<span
style='mso-tab-count:1'>              </span>The older RPis don’t have PEN pin
to reduce the power consumption, but you can manually construct it by adding a
series P-FET to the 5V main supply line. It's more than sure that your
&quot;eco feet&quot; will be less than ever. Some of the very old boards like
&quot;Pi1 B&quot; doesn't support power led turn off, so it can cause a kind of
challenge to get the system “booted and run” state.<o:p></o:p></span></p>

<p class=MsoNormal><span lang=EN-TT style='mso-ansi-language:EN-TT'>-<span
style='mso-tab-count:1'>              </span>The Rpi4 is even more smart
regarding this topic than the 3B+. Theoretically it can switch down it's
regulators by it's own, and no need these extension (unless you want alarm
function). It can be enabled somewhere it's EEPROM, but it hasn’t been tested
it due to the lack of my knowledge. What is sure, that the PEN still works on
it with the same effect of the previous model.<o:p></o:p></span></p>

</div>

</body>

</html>

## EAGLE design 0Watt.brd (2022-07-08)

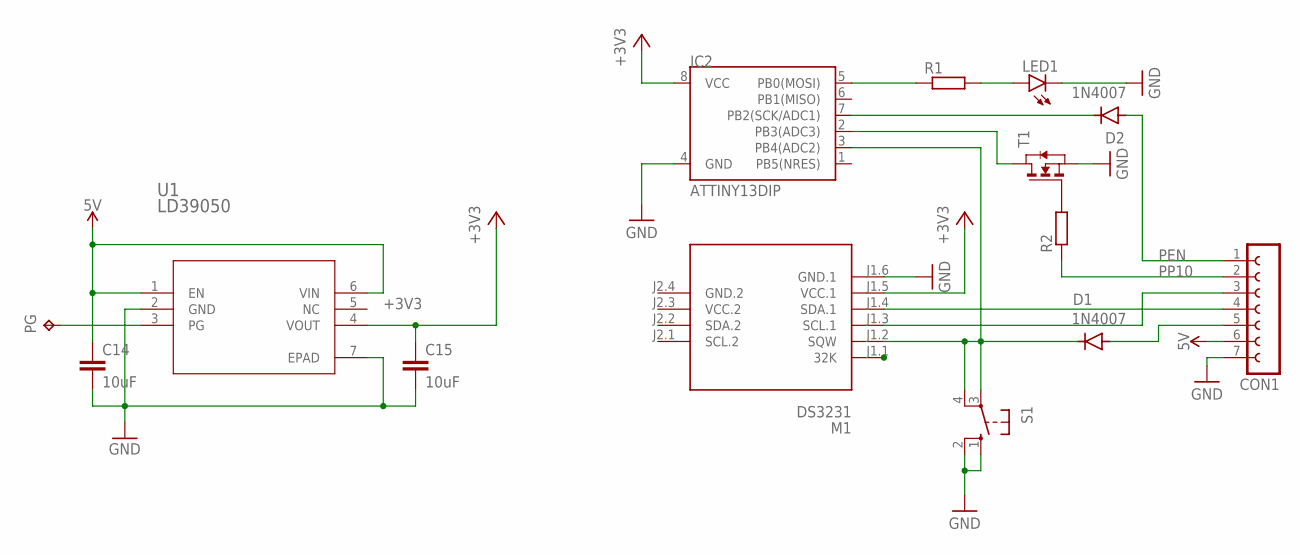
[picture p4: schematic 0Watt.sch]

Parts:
C14, C15: 10uF; C1206
CON1: FE07-1; FE07
D1, D2: 1N4007; DO-41
IC2: ATTINY13DIP; DIP08_MCU
LED1: LED5MM
M1: DS3231; RTC-DS3231-AT24C32
PG: TPB2,54; B2,54
R1: R-EU_0204/7; 0204/7
R2: R-EU_R0805; R0805
S1: 10-XX; B3F-10XX
T1: NMOSSOT23; SOT-23
U1: LD39050; DFN6_3X3_STM-M

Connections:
5V: C14.1, CON1.6, U1.1 (EN), U1.6 (VIN)
+3V3: C15.1, IC2.8 (VCC), M1.J1.5 (VCC.1), U1.4 (VOUT)
GND: C14.2, C15.2, CON1.7, IC2.4 (GND), LED1.K (C), M1.J1.6 (GND.1), S1.1 (S), S1.2 (S1), T1.2 (S), U1.2 (GND), U1.7 (EPAD)
GND.2: M1.J2.4 (GND.2)
GPIO24_: D1.C, IC2.3 (PB4(ADC2)), M1.J1.2 (SQW), S1.3, S1.4 (P1)
unnamed: D2.C, IC2.7 (PB2(SCK/ADC1))
unnamed: LED1.A, R1.2
unnamed: IC2.5 (PB0(MOSI)), R1.1
unnamed: R2.2, T1.3 (G)
unnamed: CON1.5, D1.A
unnamed: CON1.3, M1.J1.3 (SCL.1)
unnamed: CON1.4, M1.J1.4 (SDA.1)
unnamed: PG.TP, U1.3 (PG)
unnamed: IC2.2 (PB3(ADC3)), T1.1 (D)
PEN: CON1.1, D2.A
PP10: CON1.2, R2.1
VCC.2: M1.J2.3 (VCC.2)

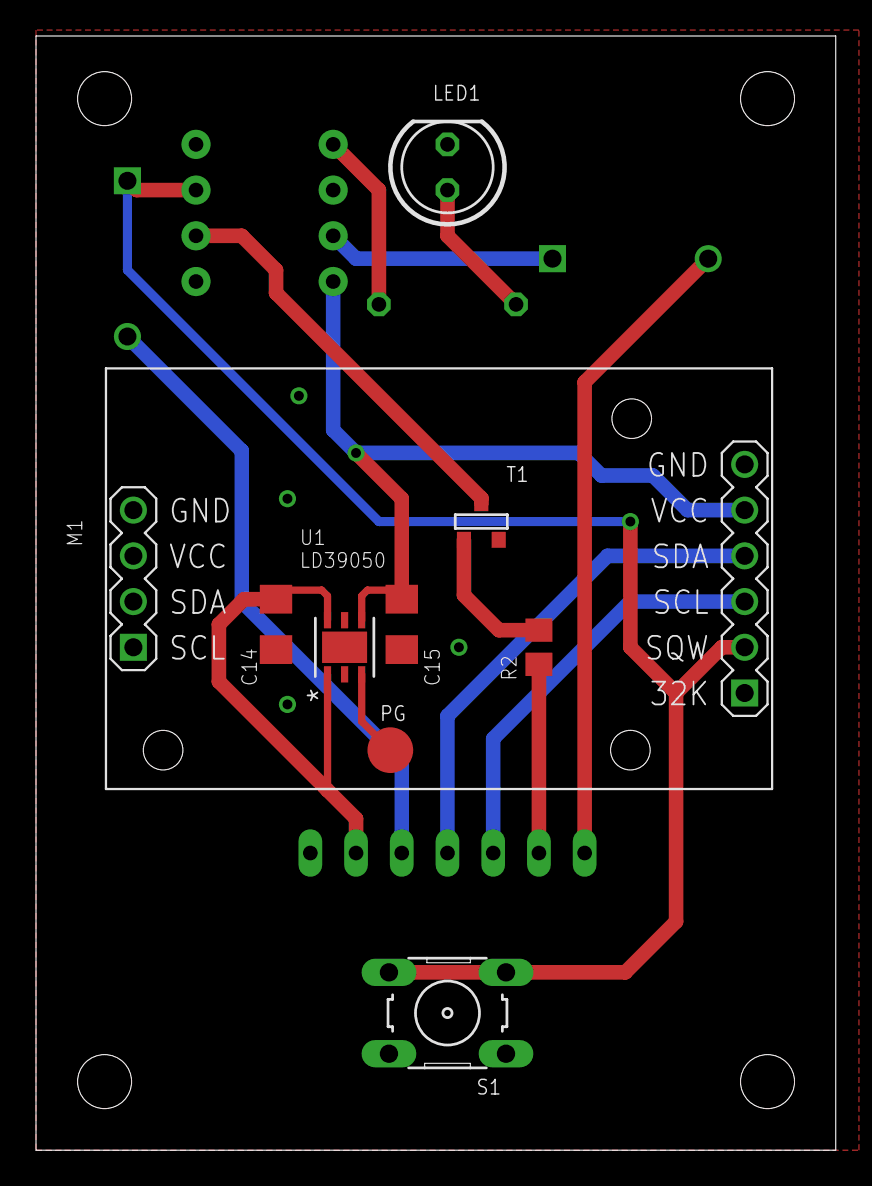
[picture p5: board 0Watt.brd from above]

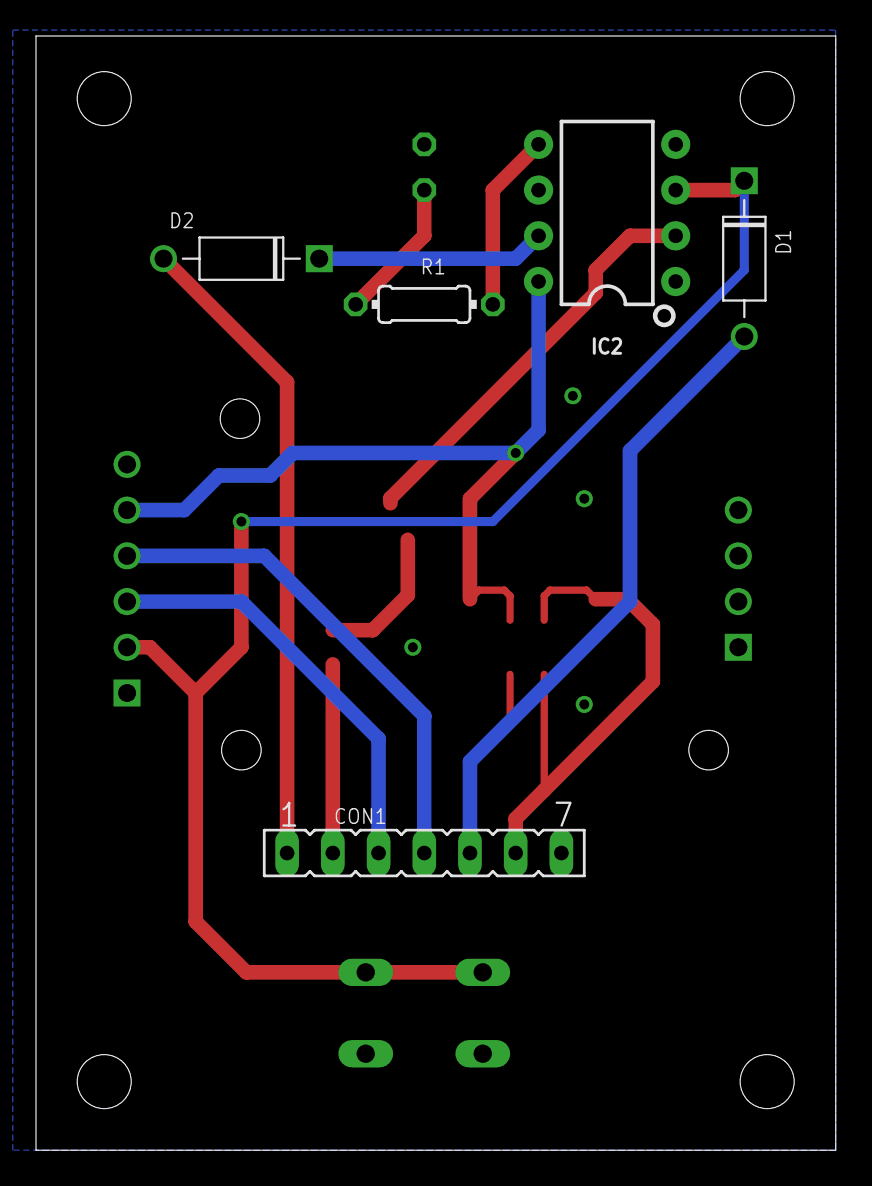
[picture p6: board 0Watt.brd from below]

Board: 2 copper layers, 44.4 x 61.9 mm, 14 parts (5 on the bottom side), 15 nets.

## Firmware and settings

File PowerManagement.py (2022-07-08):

#!/usr/bin/python3
# _*_ coding: utf-8 _*_
#coding: utf-8

import os
import time
from datetime import datetime, timedelta
import RPi.GPIO as GPIO

GPIO.setwarnings(False)
GPIO.setmode(GPIO.BCM)

Powerbutton = 24
GPIO.setup(Powerbutton, GPIO.IN, pull_up_down = GPIO.PUD_UP)

def loop():																		# Handling the manual shutdown
	
	while(1):
		if GPIO.input(Powerbutton) == False:									# If someone has been pushed it...
			os.system("sudo shutdown now &")									# I shuts down
		print("Polling the power button..")
		time.sleep(0.5)															# Reduce CPU usage
	
def setwakeup():
	
	Wakeuptime = "06:28"
			
	Datum=datetime.strftime(datetime.now(),"%Y-%m-%d")							# Getting the actual day in string format.
	Actualday = datetime.strftime(datetime.now(),"%w")							# Checking wether it is friday
	if (Actualday=='5'):														# If yes,
		Nextstartday = datetime.strptime(Datum,"%Y-%m-%d") + timedelta(days=3) 	# Skipping the wekkend days, and set it for Monday
	else:
		Nextstartday = datetime.strptime(Datum,"%Y-%m-%d") + timedelta(days=1) 	# If no set it for the next day
	Stringnextstartday = datetime.strftime(Nextstartday,"%m/%d/%Y")				# Converting from date to string fromat
	Wakeuptime=Wakeuptime+":00"
	Stringtorun="sudo rtcctl set alarm1"+" \""+Stringnextstartday+" "+Wakeuptime+"\""
	os.system(Stringtorun)
	Stringtorun="sudo rtcctl set alarm2"+" \""+Stringnextstartday+" "+Wakeuptime+"\"" # It's better to set up the alarm2 is regardless it's not currently use, because after replacing the battery it contains uninitalized data that bothers the alarm1 too.
	os.system(Stringtorun)
	os.system("sudo rtcctl on alarm1")
	print("The next weekup has been set!")

setwakeup()
loop()

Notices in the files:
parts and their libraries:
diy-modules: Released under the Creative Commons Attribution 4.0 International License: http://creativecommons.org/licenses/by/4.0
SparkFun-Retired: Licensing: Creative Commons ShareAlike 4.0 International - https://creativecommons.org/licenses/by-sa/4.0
